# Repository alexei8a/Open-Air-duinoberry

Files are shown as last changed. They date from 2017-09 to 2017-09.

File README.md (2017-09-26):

<h1 align="center">
  Open Air-duinoberry
</h1>

Sistema _IoT_ que hace interoperables datos provenientes de sensores heterogéneos

<br><br>
<p align="center">
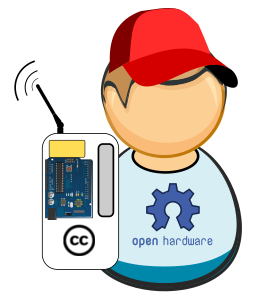
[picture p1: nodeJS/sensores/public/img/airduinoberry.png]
  
  <br><br>
</p>

## Configuración del sistema ##
  - [Introducción](#introducción)
  - [Materiales](#materiales)
  - [Requerimientos para los sensores](#requerimientos-para-los-sensores)
  - [Configuración de las tarjetas _Arduino UNO Wifi_](#configuración-de-las-tarjetas-arduino-uno-wifi)
  - [Configuración de la _Raspberry Pi 3_](#configuración-de-la-raspberry-pi-3)
  - [Descarga del respositorio y manos a la obra](#descarga-del-repositorio-y-manos-a-la-obra)
  - [_Wiki_](#wiki)
  
  ## Introducción ##

  Esta es una iniciativa, basada en el _software_  y el _hardware_ libre, que hace interoperables los datos de sensores heterogéneos en el marco de Internet de las Cosas
  <br><br>
   Aquí se presenta un sistema de medición y monitoreo de algunas de las variables ambientales relacionadas con la **_calidad del aire_**, a saber: **temperatura**, **humedad**, **presión atmosférica**, **densidad de polvo** y **concentraciones de monóxido y dióxido de carbono, metano y óxidos de nitrógeno**. 
   <br><br>
Los datos capturados por los sensores son integrados mediante el microcontrolador central de una tarjeta _Arduino_ la cual establece comunicación _Wifi_ con un servidor _Web_, embebido en una _Raspberry Pi 3_, que mediante el uso del protocolo _MQTT_ y el entorno de ejecución para _JavaScript_, _NodeJS_, facilita la inserción de los datos en una base de datos de _MongoDB_, con la cual se interactúa desde el servidor utilizando el lenguaje de intercambio _JSON_ para hacer interopreables los datos. 
   <br><br>
Además, el servidor implementa métodos para el tratamiento y visualización de datos por medio de un cliente basado en un navegador _Web_, lo cual hace que sean visibles desde diversidad de dispositivos.

  ## Materiales ##

  Para el desarrollo de este proyecto se utilizan los siguientes dispositivos:

| Dispositivo | Comunicación utilizada | Más info |
| ----- | ----- | ----- |
| Arduino UNO Wifi I | MQTT | https://store.arduino.cc/usa/arduino-uno-wifi |
| Arduino UNO Wifi II | MQTT | https://store.arduino.cc/usa/arduino-uno-wifi |
| Arduino UNO | Comunicación serial | https://store.arduino.cc/usa/arduino-uno-rev3 |
| Raspberry Pi 3 | Wifi | https://www.raspberrypi.org/products/raspberry-pi-3-model-b/ |

Los siguientes sensores son conectados a la tarjeta _Arduino UNO Wifi I_

| Sensor|  Variables medidas| Más info |
| ----- | ---- | ---- |
| MQ7 |  Concentración de monóxido de carbono | https://www.sparkfun.com/datasheets/Sensors/Biometric/MQ-7.pdf | 
| DHT11 | Temperatura y humedad relativa | http://www.micropik.com/PDF/dht11.pdf | 
| BMP180 | Presión atmosférica y temperatura | https://cdn-shop.adafruit.com/datasheets/BST-BMP180-DS000-09.pdf | 

A continuación se muestran los sensores conectados a la tarjeta _Arduino UNO Wifi II_

| Sensor|  Variables medidas| Más info |
| ----- |  ---- | ---- |
| DHT22 |  Temperatura y humedad relativa | https://www.sparkfun.com/datasheets/Sensors/Temperature/DHT22.pdf | 
| MQ135 |  Concentraciones de dióxido de carbono, óxidos de nitrógeno y amoniaco | https://www.olimex.com/Products/Components/Sensors/SNS-MQ135/resources/SNS-MQ135.pdf | 
| GP2Y1010AU0F | Densidad de polvo | https://www.sparkfun.com/datasheets/Sensors/gp2y1010au_e.pdf | 

Finalmente, el siguiente sensor se conecta a la tarjeta _Arduino UNO_

| Sensor | Variables medidas| Más info |
| ----- | ---- | ---- |
| GPS Neo-6M |  Latitud y longitud | https://www.u-blox.com/sites/default/files/products/documents/NEO-6_DataSheet_(GPS.G6-HW-09005).pdf |

  ## Requerimientos para los sensores ##

Para probar los sensores, se hace necesario crear unos pequeños programas en el entorno de desarrollo de Arduino que permitan visualizar los datos tomados en el puerto serial. [Descarga de Arduino IDE](https://www.arduino.cc/en/Main/Software).
   <br><br>
	Para mayor información sobre el entorno de programación de _Arduino_ y encontrar ejempĺos, puedes visitar el siguiente [enlace](	https://www.arduino.cc/en/Guide/HomePage)
   <br><br>
  También, se hace necesario descargar algunas librerías de Arduino para el correcto funcionamiento de los sensores enunciados anteriormente.

| Librería | Sensor que la usa | Enlace para descargar |
| ----- | ---- | ---- |
| SimpleDHT | DHT11 y DHT22 | https://github.com/winlinvip/SimpleDHT |
| SFE_BMP180 |  BMP180 | https://github.com/LowPowerLab/SFE_BMP180 |
| TinyGPSPlus |  GPS Neo-6m | https://github.com/mikalhart/TinyGPSPlus |

Estas libreras deben ser añadidas al _Arduino IDE_  mediante el **gestor de librerías** `Programa->Incluir librería->Gestionar libreras` ó `Programa->Incluir librería->Añadir librería .zip`.

  ## Configuración de las tarjetas _Arduino UNO Wifi_ ##

  Estas tarjetas deben ser configuradas para que su conexión a internet se efectúe automáticamente a la red.
	 <br><br>
  A continuación encuentras un [enlace](http://www.techmake.com/arduino-uno-wifi-intro) con la información necesaria para configurar tu _Arduino UNO Wifi_ por primera vez
	 <br><br>
	Antes de continuar con la configuración, es importante que la tarjeta se encuentre con el _Firmware_ actualizado. Puedes hacer la actualización siguiendo los pasos de este [tutorial](https://github.com/arduino-libraries/UnoWiFi-FirmwareUpdater-Plugin) 
	 <br><br>
  Posteriormente, debes configurar la conexión _MQTT_ de la tarjeta como se muestra en el siguiente [link](https://www.trojanc.co.za/2017/02/08/arduino-uno-wifi-mqtt/) 
 
   ## Configuración de la _Raspberry Pi 3_ ##
  Para comenzar a usar la tarjeta, es importante descarga el sistema operativo. En este caso, utilizamos _Raspbian_, un sistema operativo basado en _Debian_ que le da la _Raspberry_ la posibilidad de instalar _software_ que se utilizará para el desarrollo, tanto _back-end_ como _front-end_ de la aplicación _web_.
  <br><br>
  El sitio _web_ oficial de _Raspberry_ ofrece un enlace para descargar la última versión de  [_Raspbian_ Stretch](https://www.raspberrypi.org/downloads/raspbian/). Esta versión del sistema operativo se descargará en una tarjeta **micro SD clase 10** que será el disco duro del mini computador.
  <br><br>
  Después de tener el sistema operativo cargado en la _Raspberry_ se procede a hacer la instalación de las herramientas básicas para el desarrollo de la aplicación. Para ello se abre una **terminal** en la que se escribirán los siguientes comandos:
  ```
  curl -sL https://deb.nodesource.com/setup_8.x | sudo -E bash -
  sudo apt-get update && sudo apt-get upgrade
  sudo apt-get install nodejs npm 
  sudo apt-get install git
  ```
  Con esas líneas de código, realizamos una actualización de los repositorios de la _Raspberry_ e instalamos _NodeJS_, su gestor de paquetes _npm_ y el controlador de versiones _git_.
  
  La instalación de la base de datos _MongoDB_ y el **broker MQTT** _Mosquitto_ se realizan con los siguientes comandos.

  ```
  sudo apt-get update && sudo apt-get upgrade
  sudo apt-get install mongodb-server
  sudo service mongod start
  wget http://repo.mosquitto.org/debian/mosquitto-repo.gpg.key
  sudo apt-key add mosquitto-repo.gpg.key 
  cd /etc/apt/sources.list.d/
  sudo wget http://repo.mosquitto.org/debian/mosquitto-jessie.list
  sudo -i 
  sudo apt-get update && sudo apt-get upgrade
  sudo apt-get install mosquitto
  sudo apt-get install mosquitto-clients 
  ```
  
  De esta manera, la _Raspberry_ cuenta con el _software_ necesario para la implementación del sistema.
  <br><br>
  _MongoDB_ se inicia automáticamente al entrar al sistema operativo. Por el contrario _Mosquitto_ necesita ser configurado para iniciarse al acceder al sistema, mediante un _script_ que se encuentra disponible en el siguiente [enlace](https://gist.github.com/DaveThw/4396124291bb4f92b427)
    <br><br>
    En este momento, puedes revisar las versiones de cada uno de los programas instalados mediante los siguientes comandos
  
  ```
  mosquitto -v
  npm -v
  node -v
  git --version
  mongo --version
   ```
  
  <p align="center">
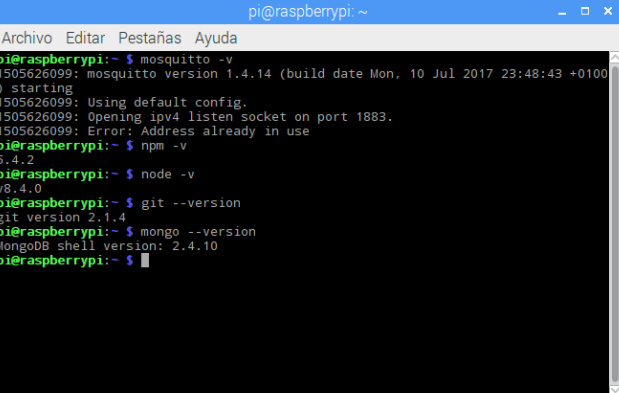
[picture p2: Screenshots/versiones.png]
  
</p>

Con la finalidad de acceder siempre a la _Raspberry_ mediante la misma dirección, se configura una _IP_ estática de acuerdo al siguiente [tutorial](https://www.vichaunter.org/como-se-hace/configurar-raspberry-pi-ip-fija-lan-wifi).

  ## Descarga del repositorio y manos a la obra ##
  
  Clona este repositorio en tu _Raspberry_ y podrás poner a funcionar los diferentes módulos del _software_ de este sistema, así como las instrucciones para poner a punto el _hardware_ utilizado:
  
  - **Módulo de registro de sensores y dispositivos**: se encuentra en la carpeta sensores
  - **Módulo de mediciones, envío de datos por MQTT y generación de alertas**: corresponde a la carpeta mqtt
  - **Módulo de visualización**: está disponible en la carpeta api
  - **Configuración del _hardware_**: contiene los códigos de programación de las tarjetas _Arduino_ y los esquemáticos realizados en _Fritzing_ para la conexión de los sensores
  
  Los tres módulos de _software_ están disponibles en la carpeta nodeJS, mientras que la sección de _harware_ se ubica en la carpeta raíz del proyecto. El contenido de estos archivos y su funcionamiento, se explican detalladamente en la [_Wiki_](https://github.com/alexei8a/Open-Air-duinoberry/wiki) del proyecto.
  <br><br>
  Carga los códigos que encuentras en la carpeta _Arduino_ en tus tarjetas _Arduino UNO Wifi_ verificando que la _IP_ a la que se conectan tus sensores vía _MQTT_ y los nombres de los tópicos para las mediciones sean los deseados.
  <br><br>
  Conecta los sensores como se puede observar en los esquemas ubicados en la carpeta _Fritzing_. Si no cuentas con el programa puedes instalarlo, haciendo click [aquí](http://fritzing.org/download/).
   <br><br>
   Abre una **terminal** y mediante el uso de comandos `cd`, ve a cada una de las carpetas correspondientes a los módulos descritos anteriormente y ejecuta `npm install`, esto descargará todos los módulos y dependencias de _NodeJS_ que se utilizan en el proyecto desde las dependencias referenciadas en los archivos **package.json**
   <br><br>
   En este momento te encuentras listo para ejecutar por primera vez la aplicación, disfrútala.

  ## _Wiki_ ##
  
En este enlace encuentras la [_Wiki_ con la documentación del proyecto](https://github.com/alexei8a/Open-Air-duinoberry/wiki)

  <br><br>

<footer  style="font-size: xx-small">
						<div align="center">
							<a href="mailto:agochoad@unal.edu.co" style="font-size: small">Contacto</a>
							<br>
								<a rel="license" href="http://creativecommons.org/licenses/by/4.0/" >
									
								</a>
								<br />
									Esta obra está bajo una <a rel="license" href="http://creativecommons.org/licenses/by/4.0/">
									Licencia Creative Commons Atribución 4.0 Internacional
								</a>.
							</br>
						</div>
					</footer>

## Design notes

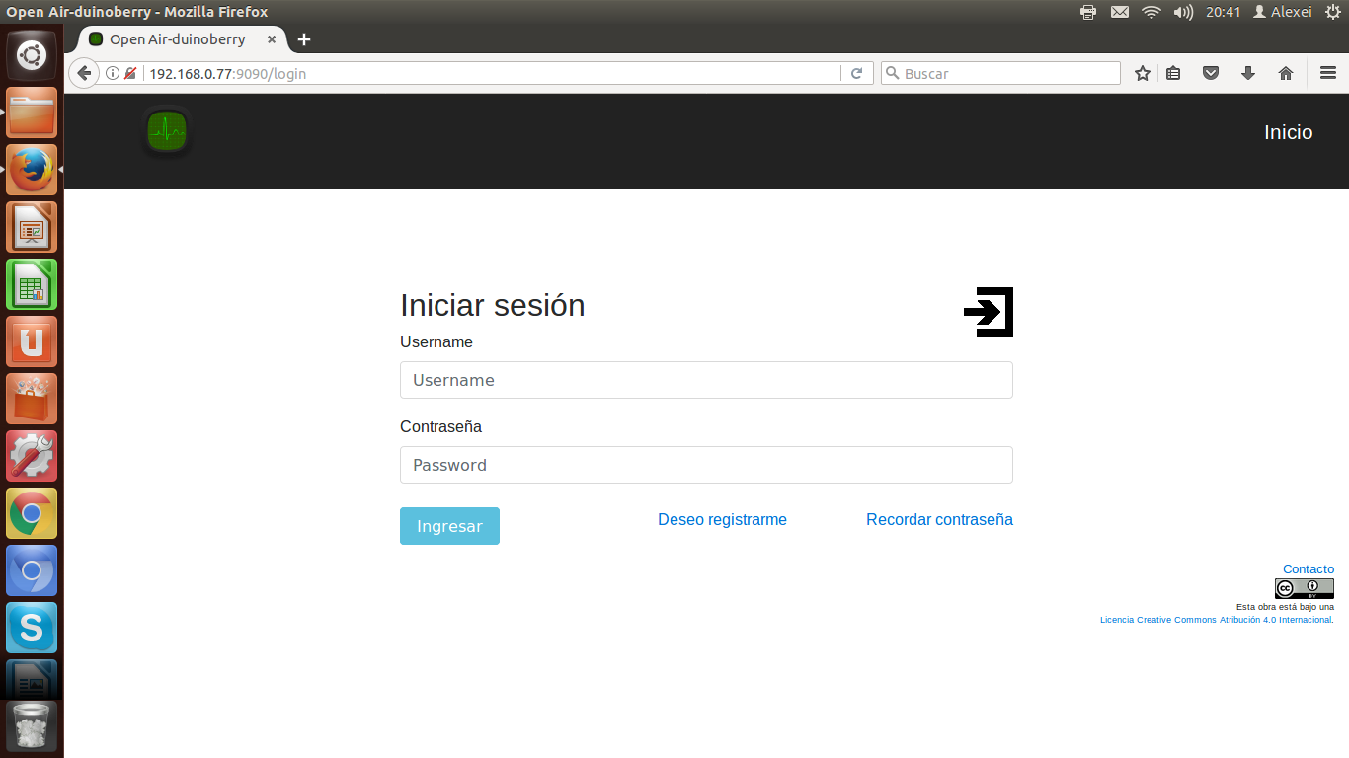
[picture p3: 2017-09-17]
Screenshots/login.png

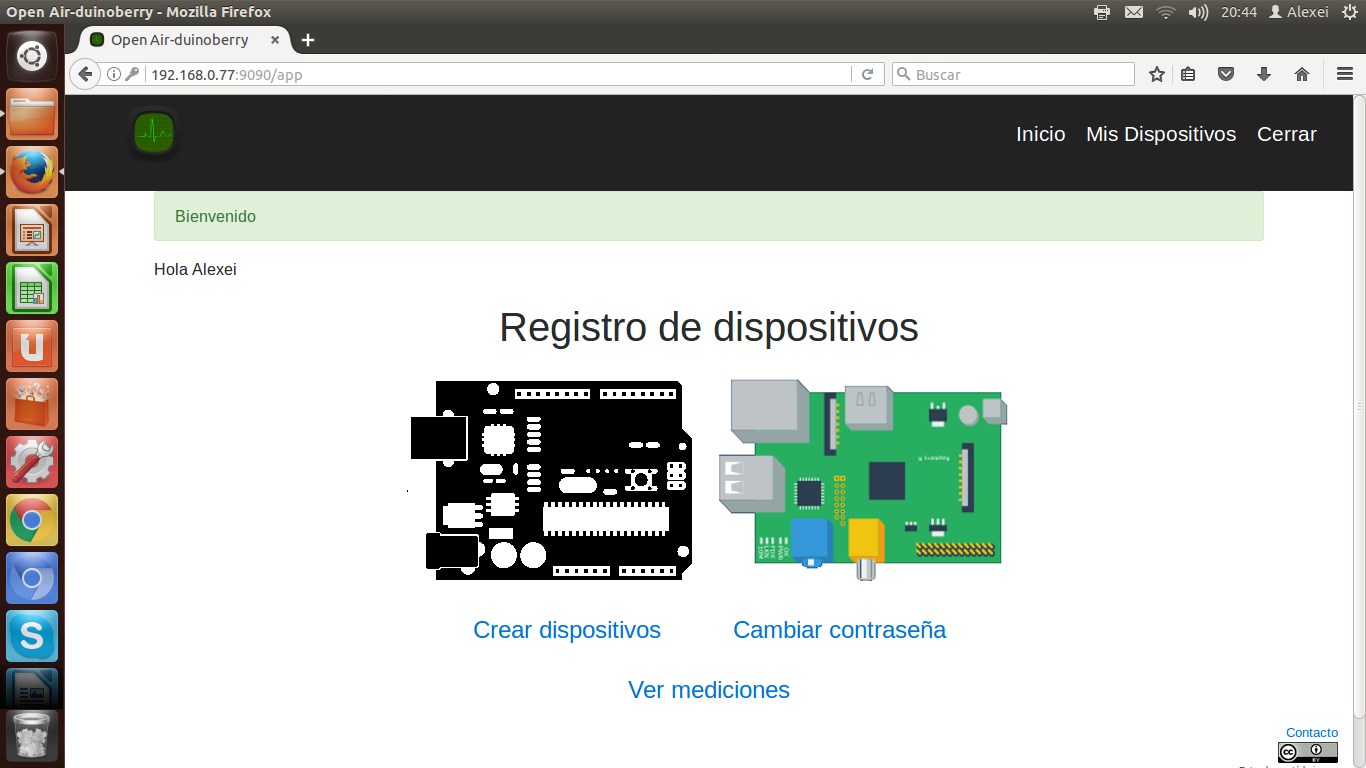
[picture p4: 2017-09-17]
Screenshots/app.png

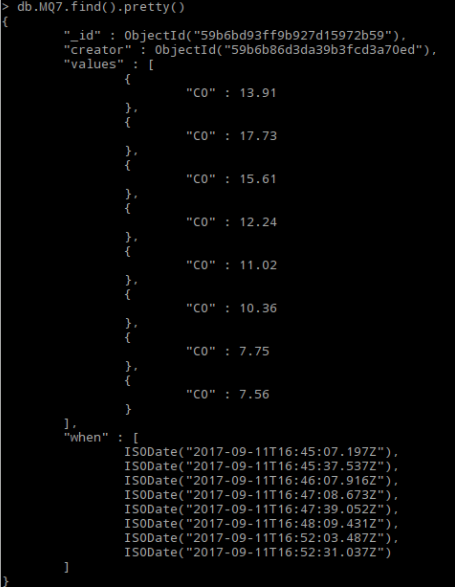
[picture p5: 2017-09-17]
Screenshots/mq7_find.png

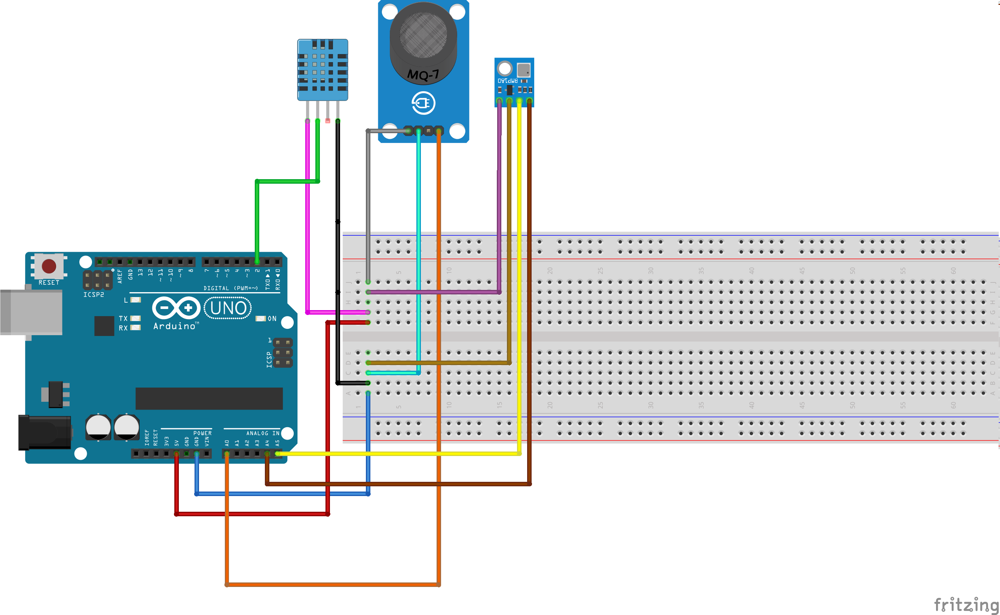
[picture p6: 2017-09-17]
Screenshots/MQ7_DHT11_BMP180_bb.png

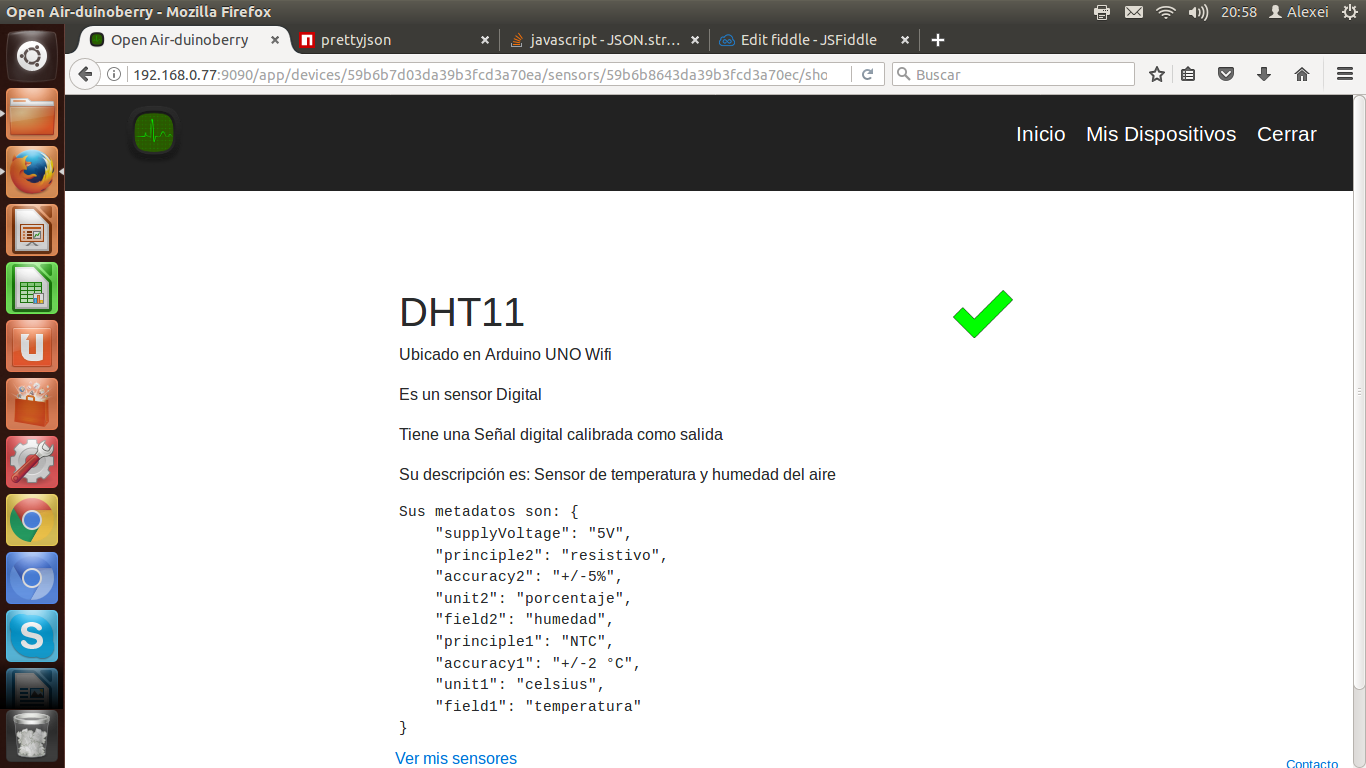
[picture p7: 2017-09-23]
Screenshots/show_sensor.png

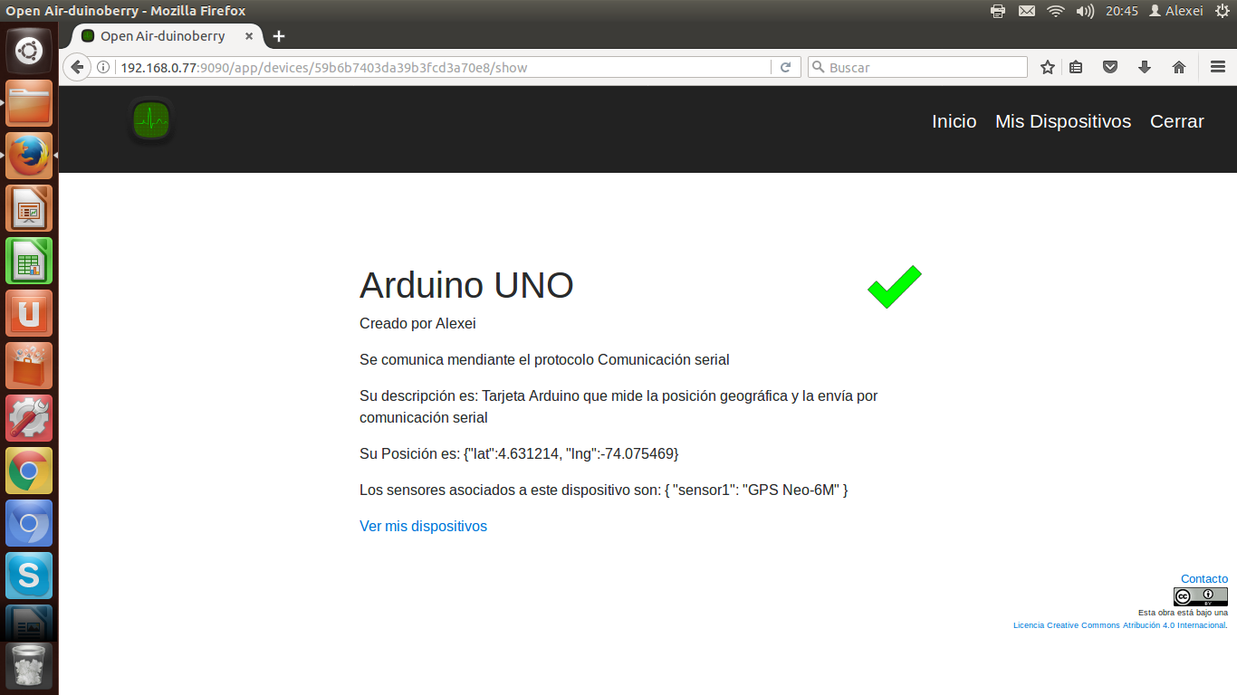
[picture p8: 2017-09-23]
Screenshots/show_device.png

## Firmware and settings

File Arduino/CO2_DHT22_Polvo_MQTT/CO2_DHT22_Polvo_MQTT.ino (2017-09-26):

#include <Wire.h>
#include <UnoWiFiDevEd.h>
#include <SimpleDHT.h>
#include <Wire.h>

#define CONNECTOR "mqtt"
#define TOPIC "arduinoUNOWifi/MQ135"
#define TOPIC2 "arduinoUNOWifi/DHT22"
#define TOPIC3 "arduinoUNOWifi/GP2Y1010AU0F"

int pinDHT22 = 4; //Conectar el sensor DHT22 al pin D4 
SimpleDHT22 dht22;

int measurePin = 1; //Conectar la salida del sensor de polvo al pin A1 de la Arduino 
int ledPower = 3;   //Conectar el pin que controla el LED del sensor de polvo a la entrada D3 de la Arduino
 


void setup() {
  Ciao.begin();
  Serial.begin(9600);
  pinMode(ledPower,OUTPUT);
}

void loop() {

//Se hacen 5 mediciones del voltaje del sensor MQ135 para evitar valores extremos causados por perturbaciones 
  float sum2=0;
  for (int i=0;i<=4;i++){
  sum2=sum2+getVoltaje();  
  }
 
  float mq135_voltaje=sum2/5;
  float mq135_resistencia = 2000*((5-mq135_voltaje)/mq135_voltaje);
  double dioxidoDeCarbono = 245*pow(mq135_resistencia/5463, -2.26);
  double oxidosDeNitrogeno = 132.6*pow(mq135_resistencia/5463, -2.74);
  double amoniaco = 161.7*pow(mq135_resistencia/5463, -2.26);

           String payload = "{";
           payload += "\"CO2\":";
           payload += dioxidoDeCarbono;
           payload += ",";
           payload += "\"NOx\":";
           payload += oxidosDeNitrogeno;
           payload += ",";
           payload += "\"NH3\":";
           payload += amoniaco;
           payload += "}";
       Serial.println(payload);

  Ciao.write(CONNECTOR, TOPIC, payload);



  float temperature = 0;
  float humidity = 0;
  int err = SimpleDHTErrSuccess;
  if ((err = dht22.read2(pinDHT22, &temperature, &humidity, NULL)) != SimpleDHTErrSuccess) {
    Serial.print("Read DHT22 failed, err="); Serial.println(err);delay(2000);
    return;
  }
  
  Serial.print("Sample OK: ");

  String payload2 = "{";
  payload2 += "\"temperatura\":";
  payload2 += (float)temperature;
  payload2 += ",";
  payload2 += "\"humedad\":";
  payload2 += (float)humidity;
  payload2 += "}";

  Serial.println(payload2);
  Ciao.write(CONNECTOR, TOPIC2, payload2);


 //Se hacen 5 mediciones de la salida del sensor de polvo para evitar valores extremos causados por perturbaciones 
  float sum=0;
  for (int i=0;i<=4;i++){
  sum=sum+getDustDensity();  
  }
  
  float dustDensity=sum/5;
  String payload3 = "{";
  payload3 += "\"densidad de polvo\":";
  payload3 += dustDensity; 
  payload3 += "}";

   Serial.println(payload3);
           
  Ciao.write(CONNECTOR, TOPIC3, payload3);

 
  delay(30000);
}

//Función que retorna el voltaje medido por el MQ135
float getVoltaje(){
  int mq135_adc = analogRead(A0);
  float mq135_voltaje = mq135_adc * (5.0 / 1023.0); // leer el valor análogo del sensor MQ135 conectado al pin A0
  return mq135_voltaje;
}

//Función que retorna la densidad de polvo en el aire
float getDustDensity(){  
  int samplingTime = 280;
  int deltaTime = 40;
  int sleepTime = 9680;
  float voMeasured = 0;
  float calcVoltage = 0;
  float dustDensity = 0;
  digitalWrite(ledPower,LOW); // encender el LED
  delayMicroseconds(samplingTime);
  voMeasured = analogRead(measurePin); // leer el valor análogo del sensor GP2Y1010AU0F conectado al pin A1
  delayMicroseconds(deltaTime);
  digitalWrite(ledPower,HIGH); // apagar el LED 
  delayMicroseconds(sleepTime);
 
  // Convierte las medidas análogas de 0 - 5V en valores enteros de 0 - 1023 
  // recupera el voltaje
  calcVoltage = voMeasured * (5.0 / 1024.0);
 
  // Ecuación lineal tomada de http://www.howmuchsnow.com/arduino/airquality/
  dustDensity = 0.17 * calcVoltage - 0.1;
 
  Serial.print("Raw Signal Value (0-1023): ");
  Serial.print(voMeasured);
 
  Serial.print(" - Voltage: ");
  Serial.print(calcVoltage);
  Serial.println();
  return dustDensity;
}


 

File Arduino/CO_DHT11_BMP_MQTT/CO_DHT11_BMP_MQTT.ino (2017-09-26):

#include <Wire.h>
#include <UnoWiFiDevEd.h>
#include <SimpleDHT.h>
#include <SFE_BMP180.h>
#include <Wire.h>


#define CONNECTOR "mqtt"
#define TOPIC "arduinoUNOWifi/MQ7"
#define TOPIC2 "arduinoUNOWifi/DHT11"
#define TOPIC3 "arduinoUNOWifi/BMP180"

int pinDHT11 = 2; //Conectar el sensor DHT22 al pin D2
SimpleDHT11 dht11;
SFE_BMP180 bmp180;//Conectar el sensor BMP180 a la Intterfaz I2C (A4 y A5 de la Arduino) 

void setup() {
  Ciao.begin();
  Serial.begin(9600);
  if (bmp180.begin())
    Serial.println("BMP180 iniciado correctamente");
  else
  {
    Serial.println("Error al iniciar el BMP180");
    while (1); // bucle infinito
  }

}

void loop() {
//Se hacen 5 mediciones de concentración de CO para evitar valores extremos causados por perturbaciones 
  float sum=0;
  for (int i=0;i<=4;i++){
  sum=sum+getCO();  
  }
  float ppm=sum/5;

  String payload = "{";
  payload += "\"CO\":";
  payload += ppm;
  payload += "}";

  Serial.println(payload);

  Ciao.write(CONNECTOR, TOPIC, payload);



  byte temperature = 0;
  byte humidity = 0;
  int err = SimpleDHTErrSuccess;
  if ((err = dht11.read(pinDHT11, &temperature, &humidity, NULL)) != SimpleDHTErrSuccess) {
    Serial.print("Read DHT11 failed, err="); Serial.println(err); delay(1000);
    return;
  }


  String payload2 = "{";
  payload2 += "\"temperatura\":";
  payload2 += (int)temperature;
  payload2 += ",";
  payload2 += "\"humedad\":";
  payload2 += (int)humidity;
  payload2 += "}";

  Serial.println(payload2);

  Ciao.write(CONNECTOR, TOPIC2, payload2);


  char status;
  double T = 0, P = 0;

  status = bmp180.startTemperature();//Inicio de lectura de temperatura
  if (status != 0)
  {
    delay(status); //Pausa para que finalice la lectura
    status = bmp180.getTemperature(T); //Obtener la temperatura
    if (status != 0)
    {
      status = bmp180.startPressure(3); //Inicio lectura de presión
      if (status != 0)
      {
        delay(status);//Pausa para que finalice la lectura
        status = bmp180.getPressure(P, T); //Obtenemos la presión
        if (status != 0)
        {

          
          String payload3 = "{";
         //payload3 += "\"presion\":";
          payload3 += "\"medidas\": [";
          payload3 += (double)P;
          payload3 += ",";
         //payload3 += "\"temp\":";
          payload3 += (double)T;
          payload3 += "]}";
         //payload3 += "}";

          Serial.println(payload3);

          Ciao.write(CONNECTOR, TOPIC3, payload3);


        }
      }
    }
  }


  delay(30000);
}

//Función que retorna la concentración de CO en el aire
float getCO(){  
  int vol= analogRead(A0); //Lee la salida analógica del MQ
  float VRL = (vol / 1023.0) * 5.0;
  float ppm = 50 * pow((((float)10000.0 / 2000.0) * ((5.0 / VRL) - 1)), -1.6) + 1.7;
  return ppm;
}

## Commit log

2017-09-10 Eliminación de fusioncharts
2017-09-10 Eliminación de fusioncharts de modulos
2017-09-10 Cambio de localhost por IP en console.log
2017-09-10 Arduino y Fritzing añadidos
    [GPS.fzz, MQ135_DHT22_GPY.fzz, MQ7_DHT11_BMP180.fzz]
2017-09-19 arreglo sensores
